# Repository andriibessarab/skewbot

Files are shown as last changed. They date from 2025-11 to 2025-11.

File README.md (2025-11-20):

# Skewb Solving Robot

media&token=d9e300c2-7d41-45e1-88ac-7afd7f9618ee"

## Purpose

The Skewb Solving Robot is designed to receieve the state of a scanned Skewb, find the solution from a list of all solutions, and execute rotations using a four-motor system.

## Features

- Website using device camera to scan Skewb state
- Autonomous Skewb solving from any valid state
- Distance sensor & Optical Sensor for cube placement verification
- LED touch sensor for start/abort control
- Encoder-based closed-looped control for rotation accuracy
    - Less cubes destroyed and faster solves

## Hardware

- 4x [VEX IQ Smart Motors](https://www.vexrobotics.com/228-2560.html)
- 1x [IQ Optical Sensor](https://www.vexrobotics.com/228-7082.html)
- 1x [IQ Distance Sensor](https://www.vexrobotics.com/228-7106.html)
- 1x [LED Touch Sensor](https://www.vexrobotics.com/228-3010.html)
- 1x [IQ Robot Brain (2nd Generation)](www.vexrobotics.com/228-6480.html)

## Software

The control system is written in C++ using Visual Studio Code along with the Vex extension. The robot pulls from a compressed bin file that contains all the optimal ways to solve a Skewb in the fewest amount of moves. This data was found through a BFS taken from the solution state and inversing the moves to find the solution at every new position reached. This data was then compressed into a bin file by bitpacking each skewb state and it's solution into unsigned 64 and 32 bit integers respectively. 

## Team

[Adam Turaj](https://github.com/AdamTuraj): Mechanical & Electrical design

[Andrii Bessarab](https://github.com/andriibessarab): Solver Algorithm, Kinematics software 

[Jason Liang](https://github.com/JasonLiang12321): Solver Algorithm, Kinematics software

[Robert Vigneron](https://github.com/robertvign): Mechanical & Electrical design

## License

Skewbot is licensed under the MIT License. See the full license text in [LICENSE](LICENSE).

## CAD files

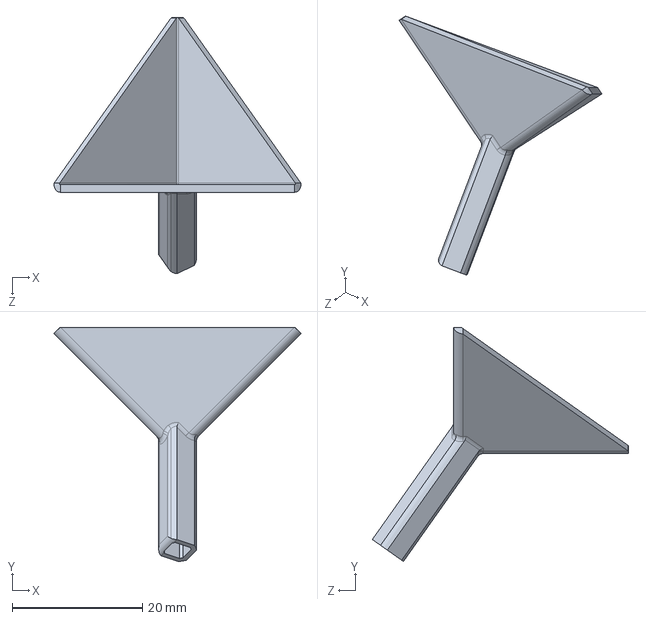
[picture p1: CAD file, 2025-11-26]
cad/Parts/Gripper.SLDPRT
38.0 x 36.0 x 39.4 mm

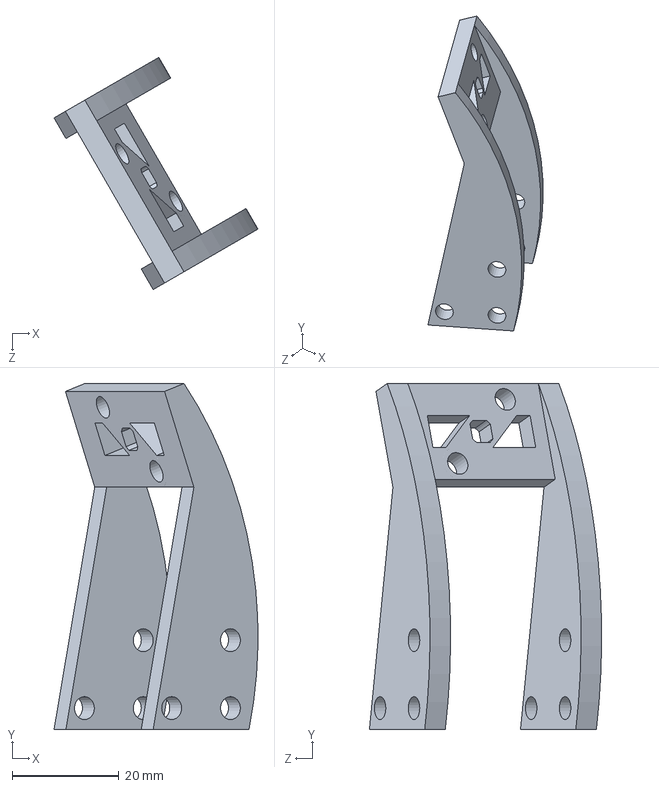
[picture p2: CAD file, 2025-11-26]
cad/Parts/Back Motor Mount.SLDPRT
38.1 x 64.7 x 43.4 mm

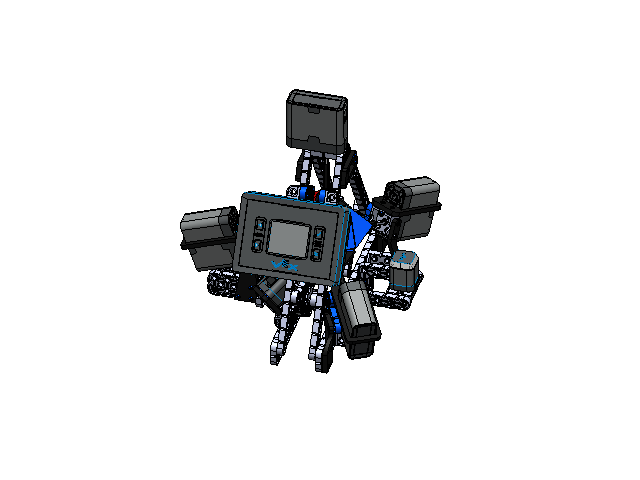
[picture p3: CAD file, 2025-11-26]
cad/skewb_solver.SLDASM
Gripper x 3
3x Motor Shaft x 3
1x1 Connector Pin (228-2500-2260) x 14
Triple 2x Wide, 2x2 Corner Connector (228-2500-1253) x 2
Side Motor Brace x 2
Top Gripper
Double 2x Wide, 2x2 Corner Connector (228-2500-220) x 3
228-2500-2236-01 Rev3_228-2500-2236-01
228-2500-2233-OVERMOLD Rev3_228-3196-2233-OVERMOLD
1x16 Beam (228-2500-014) x 4
2x18 Beam (228-2500-029) x 2
1x6 Beam (228-2500-005) x 4
0.5x Pitch Standoff (Weak) (228-2500-2268) x 4
Top Brace x 2
1x1 Connector Pin (Weak) (228-2500-2260) x 44
Double 2x Wide, 2x2 Double Offset Corner Connector (228-2500-277)(2)
2x7 Beam (228-2500-022) x 2
2x Wide, 1x2 Corner Connector (228-2500-128) x 4
Back Motor Mount
Back Motor Brace
1x2 Connector Pin (228-2500-061) x 2
2x Wide, 2x2 Corner Connector (228-2500-134)
1x Pitch Standoff (Weak) (228-2500-2269)
Small Chassis Corner Connector (228-2500-127) x 6
1x4 Beam (228-2500-003) x 2
Distance Mount
VEX IQ Optical Sensor (228-7082)
VEX IQ Distance Sensor (228-7106)
Motor Mount Left
Motor Mount Right
2x3 Right Angle Beam (228-2500-145) x 4
VEX IQ Robot Brain Gen 2 (228-6480)
Robot Battery (Li-Ion) (228-7045)
VEX IQ Touch LED (228-3010)
Double 2x Wide, 2x2 Double Offset Corner Connector (228-2500-277)
3x5 Right Angle Beam (228-2500-150) x 2
Skewb
MirrorMotor Mount Left
MirrorMotor Mount Right
MirrorDistance Mount

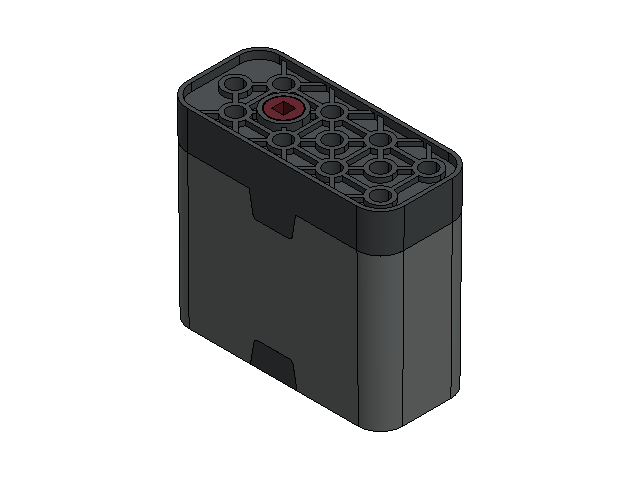
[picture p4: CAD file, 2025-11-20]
cad/Vex Parts/Smart Motor/Smart Motor.SLDASM


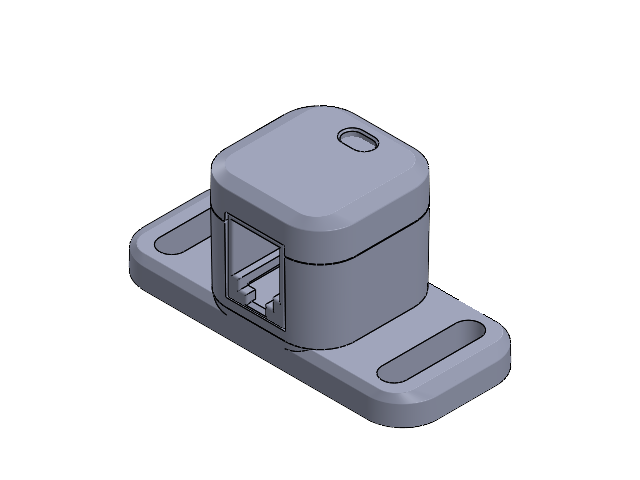
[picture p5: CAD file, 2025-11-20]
cad/Vex Parts/V5 Distance Sensor (276-4852).SLDASM
SH-55-41.step_1.step
Part15_276-4852-900 Web_1.step
276-7043-001 Web_Dual Flange_1.step
276-7043-002 Web.step
276-4852-003 Web.step
228-2677-006 Web_1.step x 4
276-4852-006 Web_1.step

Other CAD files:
cad/Vex Parts/2x Pitch Motor Shaft/2x Pitch Motor Shaft (228-2500-2234).SLDASM
cad/Vex Parts/3x Pitch Motor Shaft/3x Pitch Motor Shaft (228-2500-2236).SLDASM
cad/Parts/Motor Mount Left.SLDPRT
cad/Vex Parts/1x Pitch Standoff (Weak) (228-2500-2269).SLDPRT
cad/Vex Parts/2x Pitch Motor Shaft/228-2500-2234-01 Rev3_228-2500-2234-01.SLDPRT
cad/Vex Parts/3x Pitch Motor Shaft/228-2500-2233-OVERMOLD Rev3_228-3196-2233-OVERMOLD.SLDPRT
cad/Vex Parts/Smart Motor/228-2560-001-1.SLDPRT
cad/Vex Parts/3x Pitch Motor Shaft/228-2500-2236-01 Rev3_228-2500-2236-01.SLDPRT
cad/Vex Parts/Smart Motor/228-2560-002-1.SLDPRT
cad/Vex Parts/1x1 Connector Pin (228-2500-2260).SLDPRT
cad/Vex Parts/2x Pitch Motor Shaft/228-2500-2233-OVERMOLD Rev3_228-3445-2233-OVERMOLD.SLDPRT
cad/Vex Parts/Smart Motor/228-2560-003-1.SLDPRT
cad/Parts/Motor Mount Right.SLDPRT
cad/Parts/Back Motor Brace.SLDPRT
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

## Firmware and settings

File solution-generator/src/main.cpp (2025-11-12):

#include <fstream>
#include <iostream>
#include <queue>
#include <set>
#include <string>
#include <unordered_map>
#include <vector>

std::ofstream output("Output.txt");

std::string history = "";
std::unordered_map<std::string, std::string> history_map;
long TotalReduced = 0;

enum CENTER { W, G, O, B, R, Y };

enum CORNER { UFL, UBL, UBR, UFR, DFL, DBL, DBR, DFR };

struct skewb_state {
    std::vector<CENTER> center_colors;

    std::vector<CORNER> corner_permutations;

    std::unordered_map<CORNER, int> corner_orientations;

    skewb_state()
        : center_colors{W, G, O, B, R, Y},
          corner_permutations{UFR, UFL, UBL, UBR, DFR, DFL, DBL, DBR},
          corner_orientations{
              {UFR, 0}, {UFL, 0}, {UBL, 0}, {UBR, 0},
              {DFR, 0}, {DFL, 0}, {DBL, 0}, {DBR, 0}
          } {
    }

    void reset() { *this = skewb_state(); }

    skewb_state copy() const {
        skewb_state result;
        result.center_colors = this->center_colors;
        result.corner_permutations = this->corner_permutations;
        result.corner_orientations = this->corner_orientations;
        return result;
    }

    [[nodiscard]] bool is_equal(const skewb_state &state) const {
        return this->center_colors == state.center_colors &&
               this->corner_permutations == state.corner_permutations &&
               this->corner_orientations == state.corner_orientations;
    }

    void l_move(const bool inv) {
        if (inv) l_move(false);

        const CENTER temp = center_colors[1];
        center_colors[1] = center_colors[2];
        center_colors[2] = center_colors[5];
        center_colors[5] = temp;

        const CORNER temp_c = corner_permutations[1];
        corner_permutations[1] = corner_permutations[6];
        corner_permutations[6] = corner_permutations[4];
        corner_permutations[4] = temp_c;

        corner_orientations[corner_permutations[1]] += 2;
        corner_orientations[corner_permutations[4]] += 2;
        corner_orientations[corner_permutations[5]] += 2;
        corner_orientations[corner_permutations[6]] += 2;

        normalize_orientations();
    }

    void r_move(const bool inv) {
        if (inv) r_move(false);

        const CENTER temp = center_colors[3];
        center_colors[3] = center_colors[4];
        center_colors[4] = center_colors[5];
        center_colors[5] = temp;

        const CORNER temp_c = corner_permutations[3];
        corner_permutations[3] = corner_permutations[4];
        corner_permutations[4] = corner_permutations[6];
        corner_permutations[6] = temp_c;

        corner_orientations[corner_permutations[3]] += 2;
        corner_orientations[corner_permutations[4]] += 2;
        corner_orientations[corner_permutations[6]] += 2;
        corner_orientations[corner_permutations[7]] += 2;

        normalize_orientations();
    }

    void u_move(const bool inv) {
        if (inv) u_move(false);

        const CENTER temp = center_colors[0];
        center_colors[0] = center_colors[3];
        center_colors[3] = center_colors[2];
        center_colors[2] = temp;

        const CORNER temp_c = corner_permutations[1];
        corner_permutations[1] = corner_permutations[3];
        corner_permutations[3] = corner_permutations[6];
        corner_permutations[6] = temp_c;

        corner_orientations[corner_permutations[1]] += 2;
        corner_orientations[corner_permutations[2]] += 2;
        corner_orientations[corner_permutations[3]] += 2;
        corner_orientations[corner_permutations[6]] += 2;

        normalize_orientations();
    }

    void f_move(const bool inv) {
        if (inv) f_move(false);

        const CENTER temp = center_colors[0];
        center_colors[0] = center_colors[1];
        center_colors[1] = center_colors[4];
        center_colors[4] = temp;

        const CORNER temp_c = corner_permutations[1];
        corner_permutations[1] = corner_permutations[4];
        corner_permutations[4] = corner_permutations[3];
        corner_permutations[3] = temp_c;


        corner_orientations[corner_permutations[0]] += 2;
        corner_orientations[corner_permutations[1]] += 2;
        corner_orientations[corner_permutations[3]] += 2;
        corner_orientations[corner_permutations[4]] += 2;

        normalize_orientations();
    }

    void normalize_orientations() {
        for (auto &element: corner_orientations) {
            int &orientation_value = element.second;
            orientation_value %= 3;
        }
    }
};

std::string center_to_string(CENTER c) {
    switch (c) {
        case W:
            return "W";
        case G:
            return "G";
        case O:
            return "O";
        case B:
            return "B";
        case R:
            return "R";
        case Y:
            return "Y";
    }
    return "?";
}

std::string corner_to_string(CORNER c) {
    switch (c) {
        case UFL:
            return "UFL";
        case UBL:
            return "UBL";
        case UBR:
            return "UBR";
        case UFR:
            return "UFR";
        case DFL:
            return "DFL";
        case DBL:
            return "DBL";
        case DBR:
            return "DBR";
        case DFR:
            return "DFR";
    }
    return "?";
}

std::string get_solution(std::string history) {
    std::string solution = "";
    for (int i = history.size() - 1; i >= 0; i--) {
        // makes char Uppercase if lower, and lower if upper (inverted moves)
        std::isupper(history[i])
            ? solution += std::tolower(history[i])
            : solution += std::toupper(history[i]);
    }
    return solution;
}

std::queue<std::tuple<skewb_state, char, std::string, int> > q;

void BFS() {
    while (!q.empty()) {
        auto [CurrentState, lastmove, history, depth] = q.front();
        q.pop();
        if (depth > 11) {
            continue;
        }
        std::string solut;
        std::string scramble;

        if (lastmove == 'U') {
            CurrentState.u_move(false);
        } else if (lastmove == 'u') {
            CurrentState.u_move(true);
        } else if (lastmove == 'L') {
            CurrentState.l_move(false);
        } else if (lastmove == 'l') {
            CurrentState.l_move(true);
        } else if (lastmove == 'R') {
            CurrentState.r_move(false);
        } else if (lastmove == 'r') {
            CurrentState.r_move(true);
        } else if (lastmove == 'F') {
            CurrentState.f_move(false);
        } else if (lastmove == 'f') {
            CurrentState.f_move(true);
        }
        for (int i = 0; i < CurrentState.center_colors.size(); i++) {
            scramble += center_to_string(CurrentState.center_colors[i]);
        }
        scramble += " ";
        for (int i = 0; i < CurrentState.corner_permutations.size(); i++) {
            scramble += corner_to_string(CurrentState.corner_permutations[i]) + " ";
        }

        scramble += " ";

        for (int i = 0; i < CurrentState.corner_orientations.size(); i++) {
            scramble += std::to_string(
                CurrentState
                .corner_orientations[CurrentState.corner_permutations[i]]);
        }

        solut += history + " " + get_solution(history);
        if (history_map.find(scramble) == history_map.end()) {
            history_map[scramble] = solut;
        } else {
            TotalReduced++;
            continue;
        }

        for (char i: {'R', 'L', 'U', 'F'}) {
            if (i != static_cast<char>(std::toupper(lastmove))) {
                q.push(std::make_tuple(CurrentState.copy(), i, history + i,
                                       depth + 1));
                q.push(std::make_tuple(
                    CurrentState.copy(), static_cast<char>(std::tolower(i)),
                    history + static_cast<char>(std::tolower(i)), depth + 1));
            }
        }
    }
}

int main() {
    if (!output) {
        std::cout << "Error opening file" << std::endl;
        return 1;
    }

    skewb_state InitialState = skewb_state();
    q.push(std::make_tuple(InitialState, ' ', "", 0));
    BFS();
    int total = 0;
    for (auto i = history_map.begin(); i != history_map.end(); i++) {
        output << i->first << " " << i->second << std::endl;
        total++;
    }
    std::cout << "Total Amount Reduced: " << TotalReduced << std::endl;
    std::cout << "Total States(should be 3149280):  " << total<< std::endl;
    output.close();

    return 0;
}

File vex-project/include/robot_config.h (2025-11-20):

//----------------------------------------------------------------------------
//
//  Module:       robot_config.g
//  Description:  Header for initializing sensors and default vex stuff
//  Authors:      MTE 100 & 121 Group 15
//
//----------------------------------------------------------------------------

#ifndef ROBOT_CONFIG_H
#define ROBOT_CONFIG_H

#pragma once

#include "vex.h"
#include "skewb_motor.h"

using namespace vex;

const int TOP_MOTOR_PORT = PORT5;
const int LEFT_MOTOR_PORT = PORT1;
const int RIGHT_MOTOR_PORT = PORT7;
const int BACK_MOTOR_PORT = PORT9;
const int DISTANCE_SENSOR_PORT = PORT8;
const int TOUCH_LED_PORT = PORT12;
const int OPTICAL_SENSOR_PORT = PORT4;

extern brain Brain;
extern inertial BrainInertial;
extern distance distance_sensor;
extern touchled touch_led;
extern optical optical_sensor;

extern skewb_motor top_motor;
extern skewb_motor left_motor;
extern skewb_motor right_motor;
extern skewb_motor back_motor;

void vexcode_init(void);


#endif ROBOT_CONFIG_H

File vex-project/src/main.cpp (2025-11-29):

//----------------------------------------------------------------------------
//
//  Module:       main.cpp
//  Description:  The main entrypoint
//  Authors:      MTE 100 & 121 Group 15
//  References
//  - https://cplusplus.com/reference/cstdio/fopen/ 
//
//----------------------------------------------------------------------------

#include "vex.h"
#include "robot_config.h"
#include "state_converter.h"
#include "serial_io.h"
#include "solution_finder.h"
#include "misc_functions.h"
#include "sensor_validation.h"

using namespace vex;

int main()
{
    // Configure robot
    vexcode_init();

    // Open file
    FILE *file = fopen("SkewSolutions.bin", "rb");
    if (!file)
    {
        print_status("Couldn't open file. Abort...");
        wait(10, seconds);
        Brain.programStop();
    }
    else  // make sure file opened
    {
        // Get state from serial
        print_status("Awaiting data...");
        std::string raw_state_string = get_state_from_serial();

        // Process state
        print_status("Processing...");
        std::string state_struct_stringified = find_normalized_stringified_struct(raw_state_string);

        wait(2, seconds);

        // Obtain solution
        print_status("Searching...");
        std::string solution = find_solution(state_struct_stringified, file);
        fclose(file);
        if(solution == "")
        {
            print_status("Couldn't find solution. Abort...");
            wait(10, seconds);
            Brain.programStop(); 
        }

        wait(2, seconds);

        // Use sensor to validate cube placement
        // loops until valid
        char expected_char = state_struct_stringified[SENSOR_SIDE_CENTER_INDEX];
        validate_cube_placement(expected_char, distance_sensor, optical_sensor, touch_led);

        wait(2, seconds);

        // Wait for touch to start solve
        print_status("Ready!");
        touch_led.setColor(white);
        while (!touch_led.pressing())
        {}
        while (touch_led.pressing())
        {}
        touch_led.setColor(blue);

        // Solve
        print_status("Solving...");
        Brain.Timer.reset(); // start timer
        for (int i = 0; i < solution.size(); ++i)
        {
            if(!skewb_motor::emergency_stopped)
            {
                char move = solution[i];

                switch (move)
                {
                    case 'U':
                        back_motor.move_relative(TURN_ANGLE);
                        break;
                    case 'u':
                        back_motor.move_relative(-TURN_ANGLE);
                        break;
                    case 'L':
                        left_motor.move_relative(TURN_ANGLE);
                        break;
                    case 'l':
                        left_motor.move_relative(-TURN_ANGLE);
                        break;
                    case 'R':
                        right_motor.move_relative(TURN_ANGLE);
                        break;
                    case 'r':
                        right_motor.move_relative(-TURN_ANGLE);
                        break;
                    case 'F':
                        top_motor.move_relative(TURN_ANGLE);
                        break;
                    case 'f': 
                        top_motor.move_relative(-TURN_ANGLE);
                        break;
                    default:
                        break;
                }

                wait(50, msec);
            }
        }

        if(!skewb_motor::emergency_stopped)
        {
            // End the program
            touch_led.setColor(green);
            const double time = Brain.Timer.time() / 1000.0;
            Brain.Screen.setCursor(3,2);
            Brain.Screen.clearLine();
            Brain.Screen.print("Solved in %.3f sec",time);
            wait(20, seconds);
        }
        else
        {
            print_status("Aborting...");
            wait(2, seconds);
        }

    }

    Brain.programStop();
}

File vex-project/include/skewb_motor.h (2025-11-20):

//----------------------------------------------------------------------------
//
//  Module:       skewb_motor.h
//  Description:  Header class with separate PID for CW and CCW.
//  Authors:      MTE 100 & 121 Group 15
//
//----------------------------------------------------------------------------

#ifndef SKEWB_MOTOR_H
#define SKEWB_MOTOR_H

#pragma once

#include "vex.h"

using namespace vex;

const int TURN_ANGLE = 120;

class skewb_motor
{
private:
    motor motor_object;

    // CW
    double Kp_cw = 0, Ki_cw = 0, Kd_cw = 0;
    // CCW
    double Kp_ccw = 0, Ki_ccw = 0, Kd_ccw = 0;
    // Active
    double active_Kp = 0, active_Ki = 0, active_Kd = 0;

    double integral = 0.0;
    double prev_position = 0.0;
    double target_position = 0.0;
    const double MAX_INTEGRAL = 25.0; 
    const double TOLERANCE = 2.5;

    // returns velocity percent 
    double calculate_pid_output(double current_position)
    {
        double error = target_position - current_position;

        // integral
        // only if close to target but outside tolerance
        if (fabs(error) < 15.0 && fabs(error) > TOLERANCE) 
            integral += error;
        else if (fabs(error) >= 15.0)
            integral = 0; 
        
        // cap integral
        double integral_term = integral * active_Ki;
        if (integral_term > MAX_INTEGRAL)
            integral_term = MAX_INTEGRAL;
        if (integral_term < -MAX_INTEGRAL)
            integral_term = -MAX_INTEGRAL;

        // derivative
        double derivative = current_position - prev_position;
        prev_position = current_position;

        // generate output using ACTIVE constants
        double output = (active_Kp * error) + integral_term - (active_Kd * derivative);
        
        // clamp
        if (output > 100.0)
            output = 100.0;
        if (output < -100.0)
            output = -100.0;

        return output;
    }

    // execute actual move using pid
    void execute_move() {
        const int dt_ms = 10; 
        bool settled = false;
        int settled_count = 0;
        int timeout_counter = 0;
        const int MAX_TIMEOUT = 500; 

        prev_position = motor_object.position(degrees);

        // Check direction to use correct pid
        if (target_position >= prev_position) {
            // Moving Positive (Clockwise)
            active_Kp = Kp_cw;
            active_Ki = Ki_cw;
            active_Kd = Kd_cw;
        } else {
            // Moving Negative (Counter-Clockwise)
            active_Kp = Kp_ccw;
            active_Ki = Ki_ccw;
            active_Kd = Kd_ccw;
        }

        while (!settled && timeout_counter < MAX_TIMEOUT)
        {
            double current_pos = motor_object.position(degrees);
            double error = target_position - current_pos;

            double velocity_percent = calculate_pid_output(current_pos);

            motor_object.spin(forward, velocity_percent, percent);

            // only consider settled when no error
            if (fabs(error) <= TOLERANCE && fabs(motor_object.velocity(dps)) < 2)
                settled_count++;
            else
                settled_count = 0;

            if (settled_count > 10) 
                settled = true;

            timeout_counter++;
            wait(dt_ms, msec);

            // Always listen for pause or emerg. stop
            if(touch_led_pointer->pressing())
            {
                // stop motor
                motor_object.stop();

                // wait for person to let go and press again
                touch_led_pointer->setColor(white);
                while(!touch_led_pointer->pressing())
                {}
                while(touch_led_pointer->pressing())
                {}
                while(!touch_led_pointer->pressing())
                {}
                touch_led_pointer->setColor(blue);

                wait(500, msec);
            } 
            else if(brain_pointer->buttonUp.pressing())
            {
                emergency_stopped = true;
                settled = true; // so that we exit
            }
        }

        motor_object.stop(); 
    }

public:
    static brain* brain_pointer;          // for debugging
    static touchled* touch_led_pointer;   // for pausing
    static bool emergency_stopped;

    skewb_motor(int port, double p_cw, double i_cw, double d_cw, double p_ccw, double i_ccw, double d_ccw)
        : motor_object(port),
          Kp_cw(p_cw), Ki_cw(i_cw), Kd_cw(d_cw),
          Kp_ccw(p_ccw), Ki_ccw(i_ccw), Kd_ccw(d_ccw)

    {
        motor_object.resetPosition();
        motor_object.setStopping(hold); 
        motor_object.setMaxTorque(100, percent);
        target_position = 0.0;
        
        active_Kp = Kp_cw;
        active_Ki = Ki_cw;
        active_Kd = Kd_cw;
    }

    void setPID(bool is_clockwise, double p, double i, double d)
    {
        if(is_clockwise) {
            Kp_cw = p; Ki_cw = i; Kd_cw = d;
        } else {
            Kp_ccw = p; Ki_ccw = i; Kd_ccw = d;
        }
    }

    // move some relative amount
    void move_relative(double degrees)
    {
        target_position += degrees;
        execute_move();
    }

    // absolute position move
    void move_absolute(double degrees)
    {
        target_position = degrees;
        execute_move();
    }

    // reset
    void hard_reset_zero()
    {
        motor_object.resetPosition();
        target_position = 0;
        prev_position = 0;
        integral = 0;
    }
};

#endif SKEWB_MOTOR_H

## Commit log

2025-10-03 Fixed BFS -> removed recursion + queue and implemented with just a while loop and queue which significantly reduced recursion stacks, fixed solution alg, now also outputs in the format with the last 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
    [main.cpp]
2025-10-03 Implemented a hash_map to prevent duplicate scrambles
    [main.cpp]
2025-10-05 Transformed Output.txt into a bin file, the state and solution are encoded in a 64 bit int and a 32 int respectively. Also implemented a decoder to read in the bin file. NOTE: the bin file does not c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
2025-10-10 Revert "Format & change depth"
    Move software code into a folder
    [main.cpp]
2025-11-05 Fix api endpoint accept 'OPTIONS'
    [app.py]
2025-11-10 Define motors
2025-11-10 Define sensors
2025-11-12 Ready to switch out B-moves for F-moves as sooooon as andriis done tweaking some skweb_state items
2025-11-12 Create a custom motor struct
2025-11-13 implement switch to perform all moves
2025-11-14 Still broken, but better. Get correct string but don't find solution.
    [main.cpp, robot_config.cpp]
2025-11-14 Fix normalization. Now can do everything scan -> find solution.
    [main.cpp]
2025-11-14 Use touch sensor to begin solve
2025-11-16 Improve kinematics
2025-11-16 Tuned PID, added a Derivative term for D, Made motors stop holding if it is not turning to reduce counteracting forces. - ALL WORKS BUT NEED TO TUNE PID MORE
2025-11-18 PID :)
2025-11-19 Write function that validates cube placement using sensors
2025-11-20 pid not good :(
2025-11-20 Changes or smth idk
    [2x Pitch Motor Shaft (228-2500-2234).SLDASM, Back Motor Mount.SLDPRT, MirrorDistance Mount.SLDPRT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]
2025-11-20 update gripper
    [Gripper.SLDPRT]
2025-11-20 Seperate PIDs of each motor. Relatively consistent P controllers. Add desc. and authors to all files
2025-11-20 Add timer
2025-11-20 Tuned PID. Successful solve
2025-11-20 Tune PIDs for inverted moves.
    [main.cpp, robot_config.cpp, skewb_motor.h]
2025-11-26 Finalize CAD
    [1x Pitch Standoff (Weak) (228-2500-2269).SLDPRT, 1x1 Connector Pin (228-2500-2260).SLDPRT, 228-2500-2233-OVERMOLD Rev3_228-3196-2233-OVERMOLD.SLDPRT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]
